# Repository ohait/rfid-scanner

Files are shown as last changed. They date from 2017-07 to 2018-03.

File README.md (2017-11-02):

# rfid-scanner

Shelf cleaner for libraries

This project contains arduino code, schematics, 3d models and server implementation for a generic library rfid scanner.

It is currently a prototype for [http://www.deichman.no] and therefor only specific hardware is supported, but the plan is to make it as generic as possible

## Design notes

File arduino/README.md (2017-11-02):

# Collection of resources for the arduino project

This folder contains arduino source files, fritzing parts and 3d models.

It is completely a work in progress, so nothing is probably usable as it is, but feel free to contact me and see if I can help you.

## RFID Scanner

The main aim of this project is to design and 3d-printable rfid scanner which can be used by libraries to do inventories and check-in

It connects to a server via WiFi, and depends on it for the logic. IOW the device is pretty dumb, it scans and tells the server, and the servers tells back what to display. (cfr. [documentation](../doc/scanner_protocol.md)

The server could (and probably should) integrate with your ILS (Integrated Library System).

## Power

the device consume ~210mA when active, and ~10mA when standby

the 1200mAh LiPo battery should provide up to 6 hours of continuous scanning, and it will recharge in 10/12 hours

## installation

follow instruction here to install the board 

https://learn.adafruit.com/adafruit-feather-huzzah-esp8266/using-arduino-ide

then install adafruit GFX for the oled display

arduino ide => manage libraries => adafruit GFX

also, you will need specific library for SSD1305 and the RFID module library:

in `arduino/libraries/`

`git clone git@github.com:adafruit/Adafruit_SSD1305_Library.git`

and apply the `.patch` to the library

also get this to talk with the RFID module

`git clone git@github.com:ohait/jmy6xx.git`

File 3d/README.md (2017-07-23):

# 3d models
those models are made with Fusion 360

original files can be found here: http://a360.co/2ultijb

I'll include STL files for quick printing

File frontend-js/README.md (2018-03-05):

# Spore frontend javascript

WIP frontend view and browser for the Spore RFID scanner server and hardware

Built with [svelte](https://svelte.technology/) - self-compiling JS library

# Structure

```
public          # compiled files (html,js,css)
src
├── App.html    # Main entry and router
├── components  # Reusable components
└── pages       # Layout and API conn
```

# TODO

dependency svelte-router fix for customizable path regexp - [pending pull request](https://github.com/jikkai/svelte-router/pull/8)

for now we compile from [fork](https://github.com/bensinober/svelte-router)

# Development

You'll need nodejs and yarn (or npm)

```
yarn install
```

Workaround for building modified router

```
cd node_modules/svelte-router && yarn install && yarn run build & cd ../..
```

```
yarn run dev
```

# Deploy

To compile bundle and js:

```
yarn install && yarn run build
```

or simply `make build`

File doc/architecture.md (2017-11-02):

### Architecture

```
+--------+           
|Scanner +--+          +-------------+
+--------+  |          | Web Browser |
            v          +--+----------+
         +--------+       |
         |        | <-----+
   +-----+ Server |
   | SQL |        |
   +-----+--+-+-+-+
            | | |     +--------+
            | | +---> | SIP    |
            | |       +--------+
            | |     +---------+
            | +---> | Koha    |
            |       +---------+
            |    +----------+
            +--> | OtherILS |
                  +----------+
```

# Scanner

The scanner is the 3d printed Arduino device which scan and read rfid tags

it connects to the Server via WiFi

# Server

The Server is The central point that gather information and send instructions back to the scanner

It listen to connections from the Scanner, From web clients and it connects to ILS systems via SIP or other apis

It also connect to a SQL database

# SIP, Koha, OtherILS

Those are the systems currently in use to handle the circulation of your items

## Typical scenario

```
                  +---------+       +---------+           +-----+
                  | Scanner |       | Server  |           | ILS |
                  +---------+       +---------+           +-----+
                       |                 |                   |
      +--------------\ |                 |                   |
      | Item Scanned |-|                 |                   |
      +--------------+ |                 |                   |
                       |                 |                   |
                       | rfid data       |                   |
                       |---------------->|                   |
                       |                 |                   |
                       |                 | parse data        |
                       |                 |-----------        |
                       |                 |          |        |
                       |                 |<----------        |
                       |                 |                   |
                       |                 | info(barcode)     |
                       |                 |------------------>|  /-----------------+
                       |                 |                   |--| There is a hold |
                       |                 |    Metadata,Holds |  +-----------------+
                       |                 |<------------------|
                       |                 |                   |
                       |      info,tone  |                   |
                       |<----------------|                   |
+--------------------\ |                 |                   |
| Beep! Pick that up |-|                 |                   |
+--------------------+ |                 |                   |
                       |                 |                   |
```

In this scenario, the scanner is in inventory mode, it is scanning tags and find one.

the data is sent as-is to the server.

The server parse the data, recognize the Danish S24 standard, and fetch library + barcode

it connects to the ILS asking for information about the item by barcode

The ILS returns title, author, callnumber, and any other useful identifier.
It also add information about the status of the item, and if there are holds waiting for it.

The Server use the current location of the scanner, and the status fetched from ILS to determine the item needs to be moved elsewhere.

A message is then sent back to the client with the details of the item and a type of tone to be played.

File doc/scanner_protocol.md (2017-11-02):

# RFID communication

The scanner can talk with the server using different protocols, although right now only http is implemented.

## http
```
POST /myURL/8266_128x32 HTTP/1.1
Host: rfidscanner.mydomain.com
Length: <REQLEN>

<REQ>
```
which the server replies with
```
HTTP/1.1 200 OK
Content-Length: <RESLEN>

<RES>
```

# RFID Scanner protocol
```
HEADER:
Bytes  Desc
2      0x4242 (a protocol number)
6      MAC ADDRESS of the rfid device
32     shelf
[one or more RECORDs]

RECORD:
8      RFID tag id
1      flags (bitmask: 1 => checkin)
1      data length (N)
N      data
```
After the scanner found 1 or more RFID tags, it will send a request to the server with a header and one or more records.

anything scanned will be sent to the server.

each tags following a shelf tag belongs to that shelf, and not the initial shelf value.

for a shelf, the data will contains `SHELF#shelf.name.here`

# RESPONSE

The server might respond with:

## READ
```
READ\n
$rfid (8 bytes)\n
```
The scanner should re-scan (Reset To Ready) the tag, and read the tag data again.

## WRITE
```
WRT\n
length($rfid+$data)\n
$rfid+$data
```
The scanner need to overwrite the tag with the given RFID id, with $data. (the $rfid is 8 bytes and is the rfid id that need to be written, while $data is the data to be written)

The scanner should then read the tag again and send the content back to the server as a confirmation.

## IMG
```
IMG\n
$priority\n
$base64\n
[...]
```
Send a bitmap to the client, with the given `$priority` (Higher priority wins).

The data and number of base64 strings can be encoded differently for different devices.

## TONE
```
TONE\n
$tone\n
```
The device should play the given `$tone` sound.

right now, those sounds are supported:

|tone|description|
|----|---|
|PICK|an item needs to be picked up|
|KO|some generic errors|

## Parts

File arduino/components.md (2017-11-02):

The materials used are:

- Adafruit [Feather Huzzah 8266](https://www.adafruit.com/product/2821)
- Jinmuyu [JMY622](http://www.jinmuyu.com/hf-rfid-modules/jmy622.html)
- Jinmuyu 150x100 antenna + coax cable
- Adafruit [2.3' 128x32 OLED display](https://www.adafruit.com/product/2675)
- LiPO battery 1200mAh
- Buzzer
- Momentary Pushbutton
- Capacitory 100µF

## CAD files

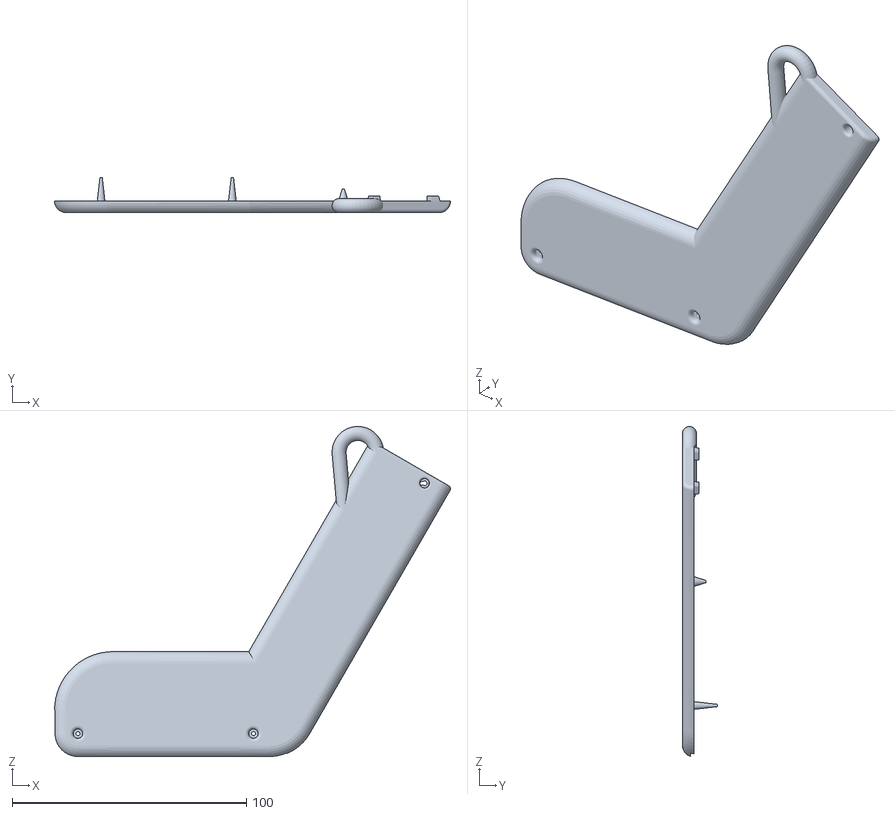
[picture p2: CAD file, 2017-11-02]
3d/Bottom.stl
168.9 x 15.0 x 140.8

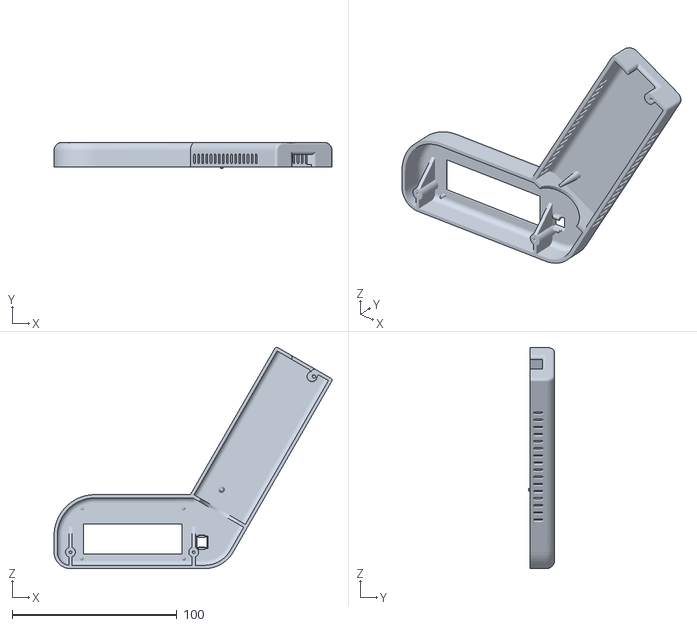
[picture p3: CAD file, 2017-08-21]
3d/Top.stl
168.9 x 16.0 x 134.5

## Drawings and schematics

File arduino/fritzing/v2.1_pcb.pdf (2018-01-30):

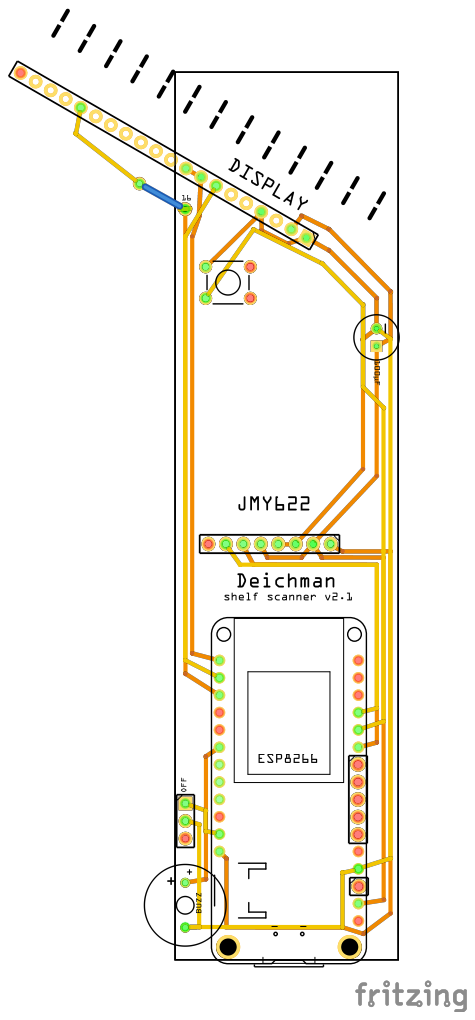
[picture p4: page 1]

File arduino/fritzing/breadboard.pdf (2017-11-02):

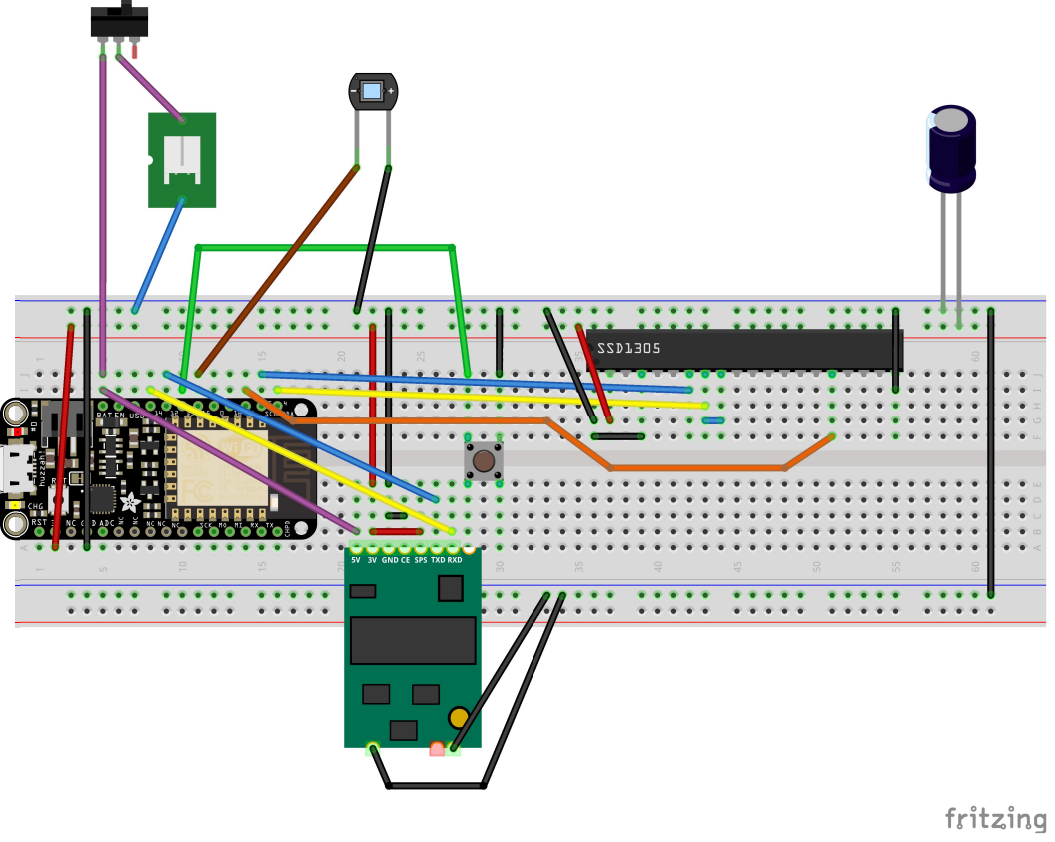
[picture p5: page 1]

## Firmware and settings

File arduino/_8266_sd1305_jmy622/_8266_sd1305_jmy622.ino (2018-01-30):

#include <Adafruit_GFX.h>
#include <gfxfont.h>
#include <Fonts/Picopixel.h>
#include <Adafruit_SSD1305.h>
#include <Wire.h>
#include <ESP8266WiFi.h>
extern "C" {
#include "gpio.h"
}
extern "C" {
  #include "user_interface.h"
}
WiFiClient client;
#include <time.h>
#include "autoupdate.h"

#define QUEUE_SIZE 32*1024
#define IDLE_TIME 180

#include <SoftwareSerial.h>
#include <jmy6xx.h>
#define RFID_RX 12
#define RFID_TX 14
SoftwareSerial SSerial(RFID_RX,RFID_TX);
JMY6xx jmy622(&SSerial);
//JMY6xx jmy622(0x50); // 0xA0/0xA1 => 0x50 in arduino world

Adafruit_SSD1305 display(2);

#define BUZZER_PIN 15
#define CHECKIN_PIN 13

#include "sounds.h"
#include "secrets.h"

// IDLE
long idle_after = 1000*IDLE_TIME;

// GLOBAL VARS
int start_block = 0;
int read_blocks = 9;
byte* send_buffer;
byte* queue;
int q_size = QUEUE_SIZE;
int q_pos = 0;
int record_size = 8+2+read_blocks*4; // align
char shelf[32];
byte wrt[64];

// DISPLAY MESSAGES
int display_prio = 0;
long display_expire = 0;

int count_total = 0;
int count_from_idle = 0;
int count_shelf = 0;

inline void shelf_reset() {
  memset(shelf, 0, 32);

  byte* record = queue+q_pos;

  memset(record, 0, 8);
  record[8] = 0; // flags
  record[9] = 32; // size
  memcpy(record+10, shelf, 32);
  q_pos += 10 + 32;
}

// CURRENT STATE
int state = 1; // 0 idle, 1 Inventory, 2 Checkin
long epoch = 0;

void checkin() {
  long now = millis();
  idle_after = now+1000*IDLE_TIME; // extends the idle time
  display_expire = 0; // clear the display

  if (state==0) {
    state = -1;
    return;
  }
  
  int prev = state;
  if (digitalRead(CHECKIN_PIN)==LOW) { // PRESS
    state = 2;
  } else {
    state = 1;
  }
}


////////////////////////////////////////////
// UPDATE DISPLAY
////////////////////////////////////////////

int wifi_gfx[] = {
  0,0,
  3,0,  3,1,  2,2,
  6,0,  6,1,  6,2,  5,3,  5,4,
  9,0,  9,1,  9,2,  8,3,  8,4,  7,5,
};

int display_cycle = 0;
void update_display() {
  if (millis() > display_expire) full_update_display();
  display_cycle++;

  yield();
  int wx = 127;
  int wy = 0;
  display.fillRect(wx-10, wy, 11, 7, BLACK);
  if (client.connected()) {
    display_cycle %=4;
    if (display_cycle<2) {
      display.drawLine(wx-4,wy, wx-4,wy+4, WHITE);
      display.drawLine(wx-5,wy+1,wx-3, wy+1, WHITE);
    } 
    if (display_cycle==1 or display_cycle==2) {
      display.drawLine(wx-1,wy, wx-1,wy+4, WHITE);
      display.drawLine(wx-2,wy+3,wx-0, wy+3, WHITE);
    }
  } else if (WiFi.status() == WL_CONNECTED) {
    int wifi = wifi_connect()*14/100;
    if (wifi>13) wifi=13;
    if (wifi<0) wifi=0;  
    display_cycle %= wifi+2;
    for (int i=0; i<display_cycle; i++) {
      display.drawPixel(wx-wifi_gfx[i*2], wy+wifi_gfx[i*2+1], WHITE);
    }
  } else {
    display_cycle %= 2;
    if (display_cycle==0) {
      display.drawLine(wx-2, wy, wx, wy+2, WHITE);
      display.drawLine(wx, wy, wx-2, wy+2, WHITE);
    } 
  }
  yield();
  display.display();
}

void full_update_display() {
  display_prio = 0;
  yield();
  display.clearDisplay();

  display.setTextSize(1);
  display.setTextColor(WHITE);
  display.setFont();
  display.setCursor(0,0);
  if (state==1) {
    display.println("Inventory");
  } else if (state==2) {
    display.println("Check IN");
  } else {
    display.println(String("State: ")+state);
  }

  yield();
  display.setTextSize(1);
  display.setTextColor(WHITE);
  display.setFont(&Picopixel);
  display.setCursor(0,14);
  display.print(count_total);
  display.print(" tags scanned");
  if (shelf[0]) {
    display.print(", ");
    display.print(count_shelf);
    display.print(" tags on shelf");
  }
  else if (count_from_idle != count_total) {
    display.print(", ");
    display.print(count_from_idle);
    display.print(" since idle");
  }

  yield();

  if (shelf[0]) { // first byte is not \0
    display.setFont(&Picopixel);
    display.setCursor(0,22);
    display.println(String("")+"shelf: "+shelf);
  }

  if (q_pos) {
    yield();
    display.setTextSize(1);
    display.setTextColor(WHITE);
    display.setFont(&Picopixel);
    display.setCursor(0,30);
    //int queue_full = q_pos *100 /q_size;
    display.print("buffer: ");
    display.print((q_pos+record_size/2)/record_size);
    display.print("/");
    display.print(q_size/record_size);
//    display.print(" (");
//    display.print(queue_full);
//    display.print("%)");
  }

  if (epoch) {
    display.setFont(&Picopixel);
    display.setCursor(110,30);
    long e = millis()/1000+epoch;
    struct tm* now = localtime(&e);
    display.print(now->tm_hour);
    display.print(now->tm_sec%2 ? " ":":");
    display.print(now->tm_min<10?"0":"");
    display.print(now->tm_min);
  }

/*
  if (wifi>99) wifi=99;
  display.setCursor(100,30);
  display.println(String("")+"WiFi:"+wifi+"%");
  */
  yield();
}

void img() {
  display.clearDisplay();
  for (int i=0; i<6; i++) {
    delay(1);
    String line = client.readStringUntil('\n');
    for (int x=0; x<128; x++) {
      char c = line[x];
      byte b = 0;
      if (c>='A' && c<='Z') b = c-'A';
      else if (c>='a' && c<='z') b = c-'a'+26;
      else if (c>='0' && c<='9') b = c-'0'+52;
      else if (c=='+') b = 62;
      else b = 63;
      delay(0);
      //Serial.print(b<16 ? ":0":":");
      //Serial.print(b, HEX);
      for (int y=0; y<6; y++) {
        if (b&(1<<y)) display.drawPixel(x, y+i*6, WHITE);
        else  display.drawPixel(x, y+i*6, BLACK);
      }
    }
  }
  display.display();
}

void error(String msg) {
  if (display_prio > 9) return;
  display_prio = 9;
  display_expire = millis()+1000*20;
  toneKO();
  Serial.println(msg);

  yield();
  display.clearDisplay();
  display.setTextSize(1);
  display.setTextColor(WHITE);
  display.setFont();
  display.setCursor(0,0);
  display.println(msg);
  display.setFont(&Picopixel);
  yield();
  display.display();
}


void info(String s) {
  if (display_prio > 1) return;
  display_prio = 1;
  display_expire = millis()+1000*20;

  yield();
  display.clearDisplay();
  display.setTextSize(1);
  display.setTextColor(WHITE);
  display.setFont();
  display.setCursor(0,0);
  display.println(s);
  yield();
  display.display();
}

void welcome() {
  display_prio = 1;
  display_expire = millis()+1000*5;

  yield();
  display.clearDisplay();
  display.setTextSize(1);
  //display.setFont(&Picopixel);
  //display.setCursor(0,4);
  display.setFont(NULL);
  display.setCursor(0,0);
  display.println("I'm Ready to scan");
  display.setCursor(0,14);
  display.println("Hold button down to");
  display.setCursor(0,24);
  display.println("Check-IN while scan");
  yield();
  display.display();
}


byte* queue_find(const byte* uid) {
  //Serial.print("queue search "); jmy622.hexprint(uid, 8); Serial.println();
  
  for(int p=0; p<q_pos;) {
    yield();
    byte* record = queue+p;

//    Serial.print("pos: 0x");
//    if (p<16) Serial.print("000");
//    else if (p<256) Serial.print("00");
//    else if (p<16*256) Serial.print("0");
//    Serial.print(p, HEX);
//    Serial.print(": ");
//    jmy622.hexprint(record, 8);
    
    if (memcmp(uid, record, 8)) {
      //Serial.println(" NO");
      p += record_size;
    } else {
      //Serial.println(" FOUND");
      return record;
    }
  }
//  Serial.println("Not in queue");
  return NULL;
}

int scan() {
  byte buf[read_blocks*4];
  if (q_pos >= q_size - record_size) {
    error("Queue full");
    return 0;
  }
  int ct = 0;
  for(; ct<100; ct++) {
    yield();
    const byte* uid = jmy622.iso15693_scan();
    
    if (!uid) break;

    if (memcmp(uid, wrt, 8)==0) { // WRT id match
      Serial.print("should write: ");
      jmy622.hexprint(uid, 8);
      Serial.println();
      jmy622.hexdump(wrt+8, read_blocks*4);
      jmy622.iso15693_write(start_block,read_blocks, wrt+8);
      toneOK();
      memset(wrt, 0, 8);
      delay(10);
    }

    yield();
    const byte* data = jmy622.iso15693_read(start_block,read_blocks);
    if (!data) break;
    yield();
    memcpy(buf, data, read_blocks*4);
    // iso_quiet() will overwrite the data, so let's have a safe copy

    Serial.print("ISO15693 ");jmy622.hexprint(uid, 8); Serial.println();
    jmy622.hexdump(buf, read_blocks*4);
    Serial.println("END");
    
    if (!jmy622.iso15693_quiet()) break;

    byte* record = queue_find(uid);
    if (record) {
    } else {
      if (q_pos + record_size > q_size) {
        error("NO MORE SPACE");
        break;
      }
      record = queue + q_pos;
      memcpy(record, uid, 8);
      q_pos += record_size;
//      Serial.print("New tag: ");
//      jmy622.hexprint(uid, 8);
//      Serial.print(", queue is ");
//      Serial.print(q_pos);
//      Serial.print("/");
//      Serial.println(q_size);
      count_total++;
      count_from_idle++;
      count_shelf++;
    }

    record[8] = (state == 2) ? 1 : 0; // 1 if checkin, 0 otherwise
    record[9] = read_blocks*4; // align

    memcpy(record+10, buf, read_blocks*4);

    if (state==2) {
       toneTock();
    } else {
       toneTick();
    }
    
//    Serial.println("record: ");
//    jmy622.hexdump(record, record_size);

    for (int i=10; i<record_size-10; i++) {
      if (memcmp((char*)(record+i), "SHELF#", strlen("SHELF#"))) continue;
      i+= strlen("SHELF#");
      strncpy(shelf, (char*)(record+i), 32);
      //Serial.println(shelf);
      count_shelf = 0;
    }
  }
  return ct;
}

void setup() {
  //Serial.begin(9600);
  Serial.begin(115200);
  SSerial.begin(19200);
  pinMode(BUZZER_PIN, OUTPUT);
  pinMode(CHECKIN_PIN, INPUT_PULLUP);
  pinMode(A0, INPUT);
//  jmy622.debug = 3;

  delay(100);
  display.begin();
  display.clearDisplay();
  display.setRotation(2);
  display.setTextSize(1);
  display.setTextColor(WHITE);
  display.setFont(&Picopixel);
  display.setCursor(0,4);
  display.print("INIT... built ");
  display.print(__DATE__);
  display.print(" - ");
  display.println(__TIME__);
  display.display();

  toneOK();
  delay(200);


  attachInterrupt(digitalPinToInterrupt(CHECKIN_PIN), checkin, CHANGE);

  WiFi.mode(WIFI_STA);
//  WiFi.setSleepMode(WIFI_LIGHT_SLEEP);
  wifi_set_sleep_type(LIGHT_SLEEP_T);
  gpio_pin_wakeup_enable(GPIO_ID_PIN(CHECKIN_PIN), GPIO_PIN_INTR_ANYEDGE);
//  WiFi.macAddress(mac);

  yield();
  delay(100);


  yield();
  Serial.println();
  Serial.println(String("INIT... build ")+__DATE__+" "+__TIME__);

  send_buffer = (byte*)malloc(q_size+8+32);
  if (!send_buffer) {
    error("Can't allocate minumum queue memory");
    while(1) delay(1000);
  }

  send_buffer[0] = 0x42;
  send_buffer[1] = 0x42;
  WiFi.macAddress(send_buffer+2);
  send_buffer[8] = '\0'; // shelf
  queue = send_buffer+8+32;
  shelf_reset();
  Serial.println(String("queue ")+(q_size/1024)+"Kb ("+(q_size/record_size)+" records)");


  jmy622.info();

  if (digitalRead(CHECKIN_PIN)==LOW) { // PRESS
    toneWAIT();
    display.clearDisplay();
    display.setTextSize(1);
    display.setTextColor(WHITE);
    display.setFont();
    display.setCursor(0,0);
    display.println("Software update");
    display.display();
    while(WiFi.status() != WL_CONNECTED) {
      delay(200);
    }
    software_update(&client, AUTOUPDATE_HOST, AUTOUPDATE_PORT, AUTOUPDATE_PATH);
  }

  delay(200);
  toneOK();
  welcome();
}

void sleep() {
  Serial.println("Zzzzz...");
  state = 0;
  shelf_reset();
  //WiFi.mode(WIFI_OFF);
  yield();
  jmy622.idle();
  yield();
  display.clearDisplay();
  display.display();
  yield();
  display.command(SSD1305_DISPLAYOFF);
  yield();
}

void wake_up() {
  Serial.println("Waking up...");
  toneOK();
  yield();
  display.command(SSD1305_DISPLAYON);
  display.clearDisplay();
  display.display();
  
  //yield();
  //WiFi.mode(WIFI_STA);
  yield();
  idle_after = millis()+1000*IDLE_TIME;
  count_from_idle = 0;
}

int prev_state = 0;
long prev_press = 0;
void loop() {
  if (state==-1) {
    wake_up(); 
    state = 1;
  }
  
  // IDLE LOOP?
  if (state==0) {
    delay(1000);
    return;
  }

  if (millis() > idle_after) {
    sleep();
    return;
  }

  long now = millis();
  if (prev_state != state) {
//    Serial.printf("change %d - %d = %d\n", now, prev_press, now - prev_press);
    if (state == 1) { // release
      if (now - prev_press < 1000) {
        shelf_reset();
      }
      prev_press = now;
    }
  }
  prev_state = state;
  
  if (scan()) {
    //Serial.println("-------------");
    idle_after = now+1000*IDLE_TIME;
  } else {
    update_display();
    wifi_recv();
    wifi_send();
    wifi_init();
  }
}

long wifi_timeout = 0;
int wifi_connect() {
  if (WiFi.status() == WL_CONNECTED) {
      int rssi = WiFi.RSSI();
      int rssi_min = -80;
      int rssi_max = -40;
      rssi = rssi < rssi_min ? 0 : rssi > rssi_max ? 100 : (rssi-rssi_min)*100/(rssi_max-rssi_min);
      return rssi;
  }

  if (millis()<wifi_timeout) {
    return 0;
  }
  yield();

#ifdef WIFI_SSID
#ifdef WIFI_PASS
  WiFi.begin(WIFI_SSID, WIFI_PASS);
  Serial.print("connecting to: "); Serial.println(WIFI_SSID);
  wifi_timeout = millis() + 1000*20; // wait 20 seconds before trying another network
  return 0;
#endif
#endif

  Serial.println("scanning WiFi networks...");
  int ct = WiFi.scanNetworks();
  for (int i=0; i<ct; i++) {
    yield();
    String ssid = WiFi.SSID(i);
    const char* pwd = wifi_pass(ssid.c_str());
    if (!pwd) {
      Serial.printf("SSID '%s' unknown\n", ssid.c_str());
      continue;
    }
    int rssi = WiFi.RSSI(i);
    rssi = rssi < -90 ? 0 : rssi > -50 ? 100 : (rssi+90)*100/(90-50);
    if (rssi<10) {
      Serial.printf("SSID '%s' is weak\n", ssid.c_str());
      continue;
    }

    WiFi.begin(ssid.c_str(), pwd);
    Serial.print("connecting to: "); Serial.println(ssid.c_str());
    wifi_timeout = millis() + 1000*20; // wait 20 seconds before trying another network
    return 0;
  }
  wifi_timeout = millis() + 1000*20; // try again in 20 seconds
  return 0;
}

long wifi_wait = 0;
long next_ping = 0;
int wifi_send() {
  if (!q_pos && millis() < next_ping) return 0; // nothing to do
  if (client.connected()) { // already waiting for an answer
    return 0;
  }
  if (wifi_connect()<30) { // poor wifi
    return 0;
  }
  if (millis()<wifi_wait) { // I should wait
    return 0;
  }
  wifi_wait = millis()+1000*1; // antiflood

  int len = q_pos+8+32;
  if (!client.connect(host(), port())) {
    Serial.println(String("client.connect(")+host()+":"+port()+") failed");
    error("server connection failed");
    return 0;
  }
  next_ping = millis()+1000*60;
  //Serial.println(String("Sending data ")+millis());
  client.print(String("POST ") + url() + " HTTP/1.0\r\n" +
               "Host: " + host() + "\r\n" + 
               "X-Scanner-Ver: "+__DATE__+" "+__TIME__+"\r\n" +
               "Content-Length: "+ (len) +"\r\n" +
               "Connection: close\r\n\r\n");

//  Serial.println("SENDING:");
//  jmy622.hexdump(send_buffer, len);
  int sent = 0;
  while(sent < len) {
    int w = client.write((const byte*)(send_buffer+sent), len-sent);
    if (w<1) {
      error("server send failed");
      wifi_wait = millis()+1000*15; // 15 seconds wait after errors
      return 0;
    }
    sent += w;
  }
//  Serial.print("sent "); Serial.print(sent); Serial.println(" bytes");
  wifi_timeout = millis()+1000*15; // read timeout
  q_pos = 0;
  memcpy(send_buffer+8, shelf, 32); // mark for the next data
}

long wifi_init_wait = 0;
int wifi_init() {
  if (client.connected()) { // already waiting for an answer
    return 0;
  }
  if (wifi_connect()<30) { // poor wifi
    return 0;
  }
  return 1;
  if (millis()<wifi_init_wait) { // I should wait
    return 0;
  }
  wifi_init_wait = millis()+1000*300; // antiflood
  if (!client.connect(host(), port())) {
    Serial.println(String("client.connect(")+host()+":"+port()+") failed");
    error("server connection failed");
    return 0;
  }
  client.print(String("GET ") + url() + " HTTP/1.0\r\n" +
               "Host: " + host() + "\r\n" + 
               "X-Scanner-Ver: "+__DATE__+" "+__TIME__+"\r\n" +
               "Connection: close\r\n\r\n");
  wifi_timeout = millis()+1000*15; 
}

int wifi_recv() {
  if (!client.connected()) return 0;
  if (millis() > wifi_timeout) {
    error("timeout waiting from server");
    client.stop();
    return 0;
  }
  if (!client.available()) return 0;

//  Serial.println("RECV");

  String cmd = client.readStringUntil('\n');
  
//  Serial.println(cmd);
  while(client.available()) {
    yield();
    String line = client.readStringUntil('\n');
    if (line.length()<2) break;
//    Serial.println(line);
  }
//  Serial.println("..");

  for(;;) {
    String msg = client.readStringUntil('\n');
    if (!msg) break;
    Serial.println("received: "); Serial.println(msg);

    if (msg.equals("")) {
      // ignore empty strings
    }
    else if (msg.equals("WRT")) {
      toneWAIT();
      int len = client.readStringUntil('\n').toInt();
      if (len>64) {
        error("WRT buffer overflow");
      } else {
        memset(wrt, 0, 64);
        client.read(wrt, len);
        Serial.println("WRT");
        jmy622.hexdump(wrt, len);
        jmy622.iso15693_ready(wrt);
      }
    }
    else if (msg.equals("LOCAL_EPOCH")) {
      String e = client.readStringUntil('\n');
      epoch = e.toInt()-millis()/1000;
    }
    else if (msg.equals("IMG")) {
//      Serial.print("IMG current display prio is: "); Serial.println(display_prio);
      if (display_prio <= 1) {
        display_prio = 1;
        display_expire = millis()+1000*15;
        img();
      } else {
        client.readStringUntil('\n');
        client.readStringUntil('\n');
        client.readStringUntil('\n');
        client.readStringUntil('\n');
        client.readStringUntil('\n');
        client.readStringUntil('\n');
      }
    }
    else if (msg.equals("PIMG")) {
      Serial.print("IMG current display prio is: "); Serial.println(display_prio);
      if (display_prio <= 5) {
        tonePICK();
        display_prio = 5;
        display_expire = millis()+1000*30;
        img();
      } else {
        client.readStringUntil('\n');
        client.readStringUntil('\n');
        client.readStringUntil('\n');
        client.readStringUntil('\n');
        client.readStringUntil('\n');
        client.readStringUntil('\n');
      }
    }
    else if (msg.equals("VIMG")) {
      Serial.print("IMG current display prio is: "); Serial.println(display_prio);
      if (display_prio <= 5) {
        toneVERIFY();
        display_prio = 5;
        display_expire = millis()+1000*30;
        img();
      } else {
        client.readStringUntil('\n');
        client.readStringUntil('\n');
        client.readStringUntil('\n');
        client.readStringUntil('\n');
        client.readStringUntil('\n');
        client.readStringUntil('\n');
      }
    }
    else if (msg.equals("SOFTWARE_UPDATE")) {
      String path = client.readStringUntil('\n');
      client.stop(); // software update take priority
      Serial.print("SOFTWARE UPDATE: "); Serial.println(path);
      error("Automatic Update\nPlase wait\n(several minutes)");
      software_update(&client, AUTOUPDATE_HOST, AUTOUPDATE_PORT, path.c_str());
      error("Update failed");
      delay(2000);
      ESP.restart();
    }
    else if (msg.equals("END")) {
      break;
    }
    else {
      Serial.println(String("UNKNOWN CMD: '")+msg+"'");
      wifi_wait = millis()+1000*10;
      break;
    }
  }
  client.stop();
  
  return 1;
}

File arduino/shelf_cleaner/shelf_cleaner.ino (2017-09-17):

/*
 * Feather HUZZAH Wifi
 * 
 *           |USB|
 *     RST*  \   / +  
 *     3v3*        /--
 *       -*         BATTERY
 *     GND*        \--
 *      17*         *VBAT
 *       -*         *En
 *       -*         *VBUS
 *       -*         *14
 *       -*         *12
 *       -*         *13
 * TX===14*         *15
 * buz==13*         *0
 * RX===12*         *16
 *       3*         *2
 *       1*         *5
 *     CHP*         *4
 *  
 * SoftSerial speak with the RFID chip using 12,14
 * Buzzer use pin 13 to give user feedback
 * 
 * TODO: use OLED FeatherWing, will be I2C on 4/5 (SDA/SCL)
 */

//#define DEBUG
// fancy debug on serial port
#ifdef DEBUG
#define SERIALDEBUG(line) Serial.println(String("")+millis()+" "+line); //*/
#define SERIALHEXDUMP(out, len) serialhexdump(out, len); //*/
#else
#define SERIALDEBUG(line) //*/
#define SERIALHEXDUMP(out, len) //*/
#endif

#include <ESP8266WiFi.h>
WiFiClient client;
int client_work = 0;
long wifi_timeout = 0;

#include <SoftwareSerial.h>
SoftwareSerial RFID(12, 14); // RX, TX to the RFID module
byte inventory[] = { 0x00, 0x04, 0x00, 0x5C };
byte read_block[] = { 0x00, 0x06, 0x00, 0x54, 0, 9 };
byte stay_quiet[] = { 0x00, 0x04, 0x00, 0x5d };

#include <SPI.h>
#include <Wire.h>
#include <Adafruit_SSD1306.h>

#define OLED_RESET 3
Adafruit_SSD1306 display(OLED_RESET);

#if (SSD1306_LCDHEIGHT != 32)
#error("Height incorrect, please fix Adafruit_SSD1306.h!");
#endif

#include "secrets.h"
const char* ssid_pwd(const char* ssid) {
  if (strcmp(ssid, "oha.it")==0) return OHAIT_P;
  if (strcmp(ssid, "hovedbib")==0) return HOVEDBIB_P;
  return 0;
}

char* _host     = "beta.oha.it";
int   _port     = 80;
char* _url      = "/arduino/rfid/";

const char* host() {
//  if (WiFi.SSID().equals("hovedbib")) return HOVEDBIB_HOST;
  return _host;
}

const char* hhost() { // host name sent in headers, overriding hostname used to connect
  //if (WiFi.SSID().equals("hovedbib")) return "foo";
  return host();
}

int port() {
  //if (WiFi.SSID().equals("hovedbib")) return 80;
  return _port;
}

const char* url() {
  return _url;
}


byte mac[6];

#define QUEUE_SIZE (40*500)
// QUEUE of tags found, ready to send
byte* _queue = (byte*)malloc(QUEUE_SIZE+40);
byte* queue = _queue+40;
int queue_count = 0;
byte* pos = queue;

// buffer for IO
byte* out = (byte*)malloc(1024);

// to write
byte* wid = (byte*)malloc(256);
#define TAG_READ_SIZE (8)
byte* rid = (byte*)malloc(8*TAG_READ_SIZE);

// shelf
char* shelf = (char*)malloc(32);
long shelf_expire = 0;

void btnA() {
  shelf_expire = 1;
}

void setup() {
  Serial.begin(9600);
  RFID.begin(19200);
  memset(wid, 0, 256);
  memset(rid, 0, 8*TAG_READ_SIZE);
  strcpy(shelf, "");
  delay(200);
  pinMode(0, INPUT); digitalWrite(0, HIGH);
  attachInterrupt(digitalPinToInterrupt(0), btnA, RISING);
//  pinMode(2, INPUT); digitalWrite(2, HIGH);
//  attachInterrupt(digitalPinToInterrupt(16), btnB, RISING);
//  pinMode(16, INPUT); digitalWrite(16, HIGH);
//  attachInterrupt(digitalPinToInterrupt(2), btnC, RISING);
  
  Serial.println(String("INIT... build ")+__DATE__+" "+__TIME__);

  display.begin(SSD1306_SWITCHCAPVCC, 0x3C);
  display.clearDisplay();
  display.setTextSize(2);
  display.setTextColor(WHITE);
  display.setCursor(0,0);
  display.println("Deichman");
  display.setTextSize(1);
  display.println("Shelf Cleaner");
  display.println(String("build ")+__DATE__);
  display.display();

  WiFi.mode(WIFI_STA);
  WiFi.macAddress(mac);

  byte info[] = { 0x00, 0x04, 0x00, 0x10};
  if(rfid_req(info, out)>10) {
    //toneACK();
  } else {
    Serial.println("Can't find the RFID reader");
    toneKO();
    display.clearDisplay();
    display.setTextSize(2);
    display.setTextColor(WHITE);
    display.setCursor(0,0);
    display.println("NO RFID MODULE");
    display.display();
    while(1) delay(60000);
  }
  delay(1000);
  wifi_connect();
  //toneOK();
}

long display_expire = 0;
int display_level = 0;
void loop() {
  delay(5);
  if (shelf_expire==0) {
    delay(200);
  }
  long t0 = millis();
  if (shelf_expire && t0>shelf_expire) {
    memset(shelf, 0, 32);
    shelf_expire = 0;
    toneNO();
  }
  
  if (t0 > display_expire) {
    display.clearDisplay();
    display.setTextSize(1);
    display.setCursor(0,0);
    display.setTextColor(WHITE);
    display.println(shelf);
    display.println();
    if (WiFi.status() == WL_CONNECTED) {
      display.print(String("SSID ")+WiFi.SSID());
      int rssi = WiFi.RSSI();
      rssi = rssi < -90 ? 0 : rssi > -50 ? 100 : (rssi+90)*100/(90-50);
      display.println(String(" ")+rssi+"%");
    } else if (wifi_timeout) {
      display.println(String("Connecting"));
    } else {
      display.println(String("OFFLINE "));
    }
    display.println(String("")+queue_count+" queued ("+(100*(pos-queue)/QUEUE_SIZE)+"%)");
    display.display();
    display_level = 0;
  }

  int i;
  for (i=0; i<100; i++) {
    int r = rfid_req(inventory, out);
    if (r<8) break;

    // current tag needs to be written
    if (memcmp(out+5, wid, 8)==0) {
      write_tag();
      return;
    }

    Serial.print("RFID: "); hex2str(out+5, 8); Serial.println();

    // should I read the tag blocks?
    int must_read = 1;
    if (WiFi.status() != WL_CONNECTED) must_read++;
    if (!must_read) {
      for (int i=0; i<TAG_READ_SIZE; i++) {
        if (memcmp(out+5, rid+8*i, 8)==0) {
          must_read++;
          memset(rid+8*i, 0, 8); // remove
          break;
        }
      }
    }
    if (is_queued(out+5)) {
      must_read = 0;
    }
    if (must_read) {
      queue_count++;
      memcpy(pos, out+5, 8); // rfid tag id
      pos[8] = 0; // flags TODO if button, send check-in
      pos += 9;
      int len = rfid_req(read_block, out);
      //SERIALHEXDUMP(out, len);

      if (len>128) { // IGNORE
      } else if (len<4) { // IGNORE
      } else if (memcmp(out+4, "SHELF#", 6)==0) {
        pos[-1] = 128; // raise shelf flag
        pos[0] = len-4; pos++;
        memcpy(pos, out+4, len-4); // skip first 4 bytes (len+frame+cmd)
        pos += len-4;

        memcpy(shelf, out+4+6, 32-6);
        shelf_expire = millis() + 1000*60;
        // TODO fetch more data, and search for SSID/PWD
        toneOK();
      }
      else {
        pos[0] = len-4; pos++;
        memcpy(pos, out+4, len-4); // skip first 4 bytes (len+frame+cmd)
        pos += len-4;
        if (shelf_expire) {
          shelf_expire = millis() + 1000*60;
          toneTick();
        } else {
          toneTock();
        }
      }
    } 
    else { // only the tag id will be sent
      queue_count++;
      memcpy(pos, out+5, 8); // rfid tag id
      pos[8] = 0; // flags
      pos[9] = 0; // length
      pos += 10;
      toneTick();
    }
    // tell the CURRENT_TAG to stay quiet (until it exits the field)
    // so we can scan other tags
    rfid_req(stay_quiet, out);
  }

  if (i>0) { // if 1 or more tags were scanned, just go back scanning for more!
    //Serial.println(String("SCANNED ")+i+" ITEM. "+(millis()-t0));
    return;
  }
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

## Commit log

2017-06-29 3d gun
    [BODY.stl, LID.stl]
2017-06-29 Arduino code
2017-06-29 updated stl files
    [BODY.stl, LID.stl]
2017-07-11 only 5 seconds wait if connection fail
    [shelf_cleaner.ino]
2017-07-12 don't try to connect if signal too low
    [shelf_cleaner.ino]
2017-07-17 rfid scanner class to parse data from the arduino
2017-07-23 New design
    [BODY.stl, Bottom.stl, LID.stl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]
2017-08-21 updated design to fit corrected measures of the display
    [Bottom.stl, Top.stl]
2017-08-28 new hardware, ssd1305 and I2C
2017-10-03 better handling of button press time
2017-10-03 adding fritzing files
    [scanner.fzz]
2017-10-09 new version, only partial PCB
    [v2.fzz]
2017-10-10 move cap away from battery space
    [v2.fzz]
2017-10-10 arranging tracks to stay away from wifi antenna
    [v2.fzz]
2017-10-11 minor fixes
    [v2.fzz]
2017-11-02 new stl files
    [Bottom.stl]
2017-11-07 new version of the PCB using EN pin
    [v2.1.fzz]
2017-11-21 vimg and shelf reset record
    [_8266_sd1305_jmy622.ino]
2017-11-21 double click to reset shelf
    debouncing code still a bit finicky
    minor changes
    [_8266_sd1305_jmy622.ino]
2018-01-31 make decorators more powerful
2018-03-26 attach the search component to the item view
